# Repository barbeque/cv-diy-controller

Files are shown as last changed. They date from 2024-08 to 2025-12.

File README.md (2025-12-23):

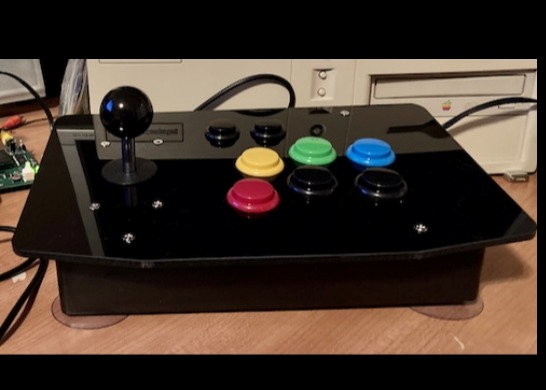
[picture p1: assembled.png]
The assembled joystick.


## Introduction

The stock "Hand Controller" on the ColecoVision is prone to wearing out. It is also uncomfortable to play for long periods of time, due to the position that your hand has to be placed into.

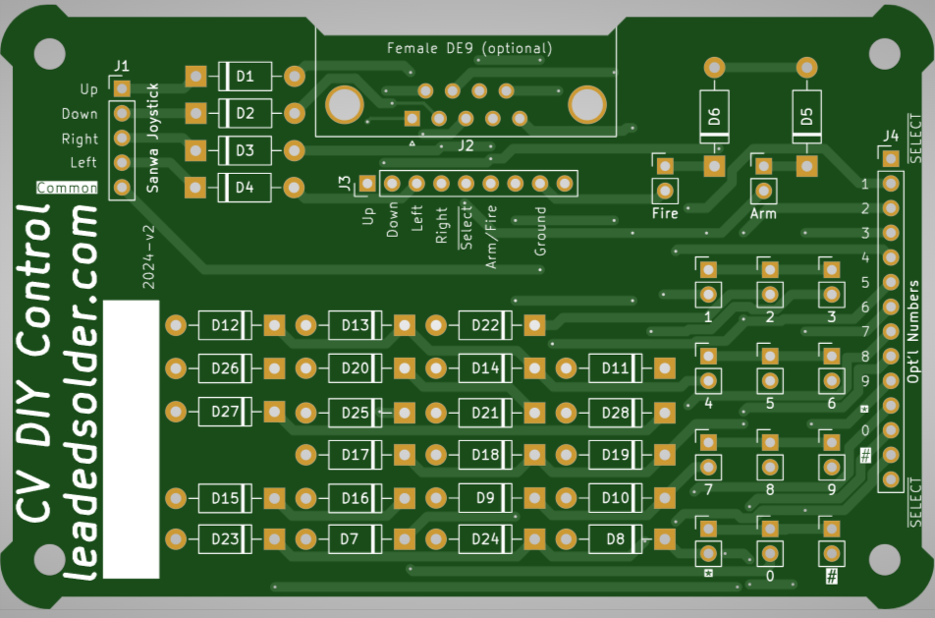
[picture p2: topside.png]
The topside of the PCB.


This PCB allows you to use a generic "arcade joystick kit" to build an arcade-style joystick for the ColecoVision. It makes it much easier to play.

## Version History
### 2024-v2
Diodes were flipped to actually make the PCB work properly. Mea culpa!

Board was shrunk below 100x100mm to make ordering cheaper.

## Support
If you liked this joystick, please [consider supporting my Patreon](https://www.patreon.com/leadedsolder) or [buying me a ko-fi](https://ko-fi.com/leadedsolder). Every penny goes back into making more free and open-source hardware for old computers and game systems.

## Ordering the PCB
Download the Gerber files from [the Releases page](/releases) and send them to your favourite PCB manufacturer.

You can also [order the PCB from PCBWay directly](https://www.pcbway.com/project/shareproject/ColecoVision_DIY_arcade_joystick_PCB_e30ae2ff.html); I will receive a small cut of this price.

## Bill of Materials

| Part | Quantity | Comment |
|---|---|---|
| 1n5817 Schottky diode  | 28 | You can also use 1n4148, which is cheaper |
| A-DF 09 A/KG-T2S male DE9 | 1 | For use with a Sega extension cable. |
| 0.1" male pin headers  | At least 40 | |

## Required Joystick Parts

In addition to the parts listed in the bill of materials, you will need to make sure that your joystick kit comes with buttons, and a Sanwa-style joystick.

The number pad can either be wired to individual buttons (I recommend wiring "1" and "*" at the very least) but some number pads will come with a multi-pin connector, which can then use the large connector on the side.

The female DE9 connector is meant to be used with a Sega Genesis controller extension cable, which is available on many sites like eBay and AliExpress. This will provide the correct pinout to the ColecoVision without having to do any messy cable-building, and you can keep the male end of the cable inside the joystick housing.

You can also wire your own cable into the 9-pin header in the middle of the board.

## Assembly

Break up your pin headers and solder them into the 2-pin connectors for number pad, ARM and FIRE buttons, and the joystick.

Fill every diode space with diodes. If you can't find 1n5817 Schottky diodes, it is OK to use the much more common (and cheaper) 1n4148.

Now it's time to assemble the joystick: put the case together according to the instructions that came with your joystick kit. Once that's done, remove the lid and install the PCB.

Check your joystick's connector. You may need to use a continuity test on your multimeter to figure out which pin is ground and which pins correspond to the directional microswitches. Make sure to install the stick the same way that the label on the board indicates.

Buttons can be connected to the 2-pin pin headers in either orientation: they are not polarized.

## Testing

The best game to test this joystick with is Frenzy, because it has some challenging diagonal directions in order to aim and fire around corners.

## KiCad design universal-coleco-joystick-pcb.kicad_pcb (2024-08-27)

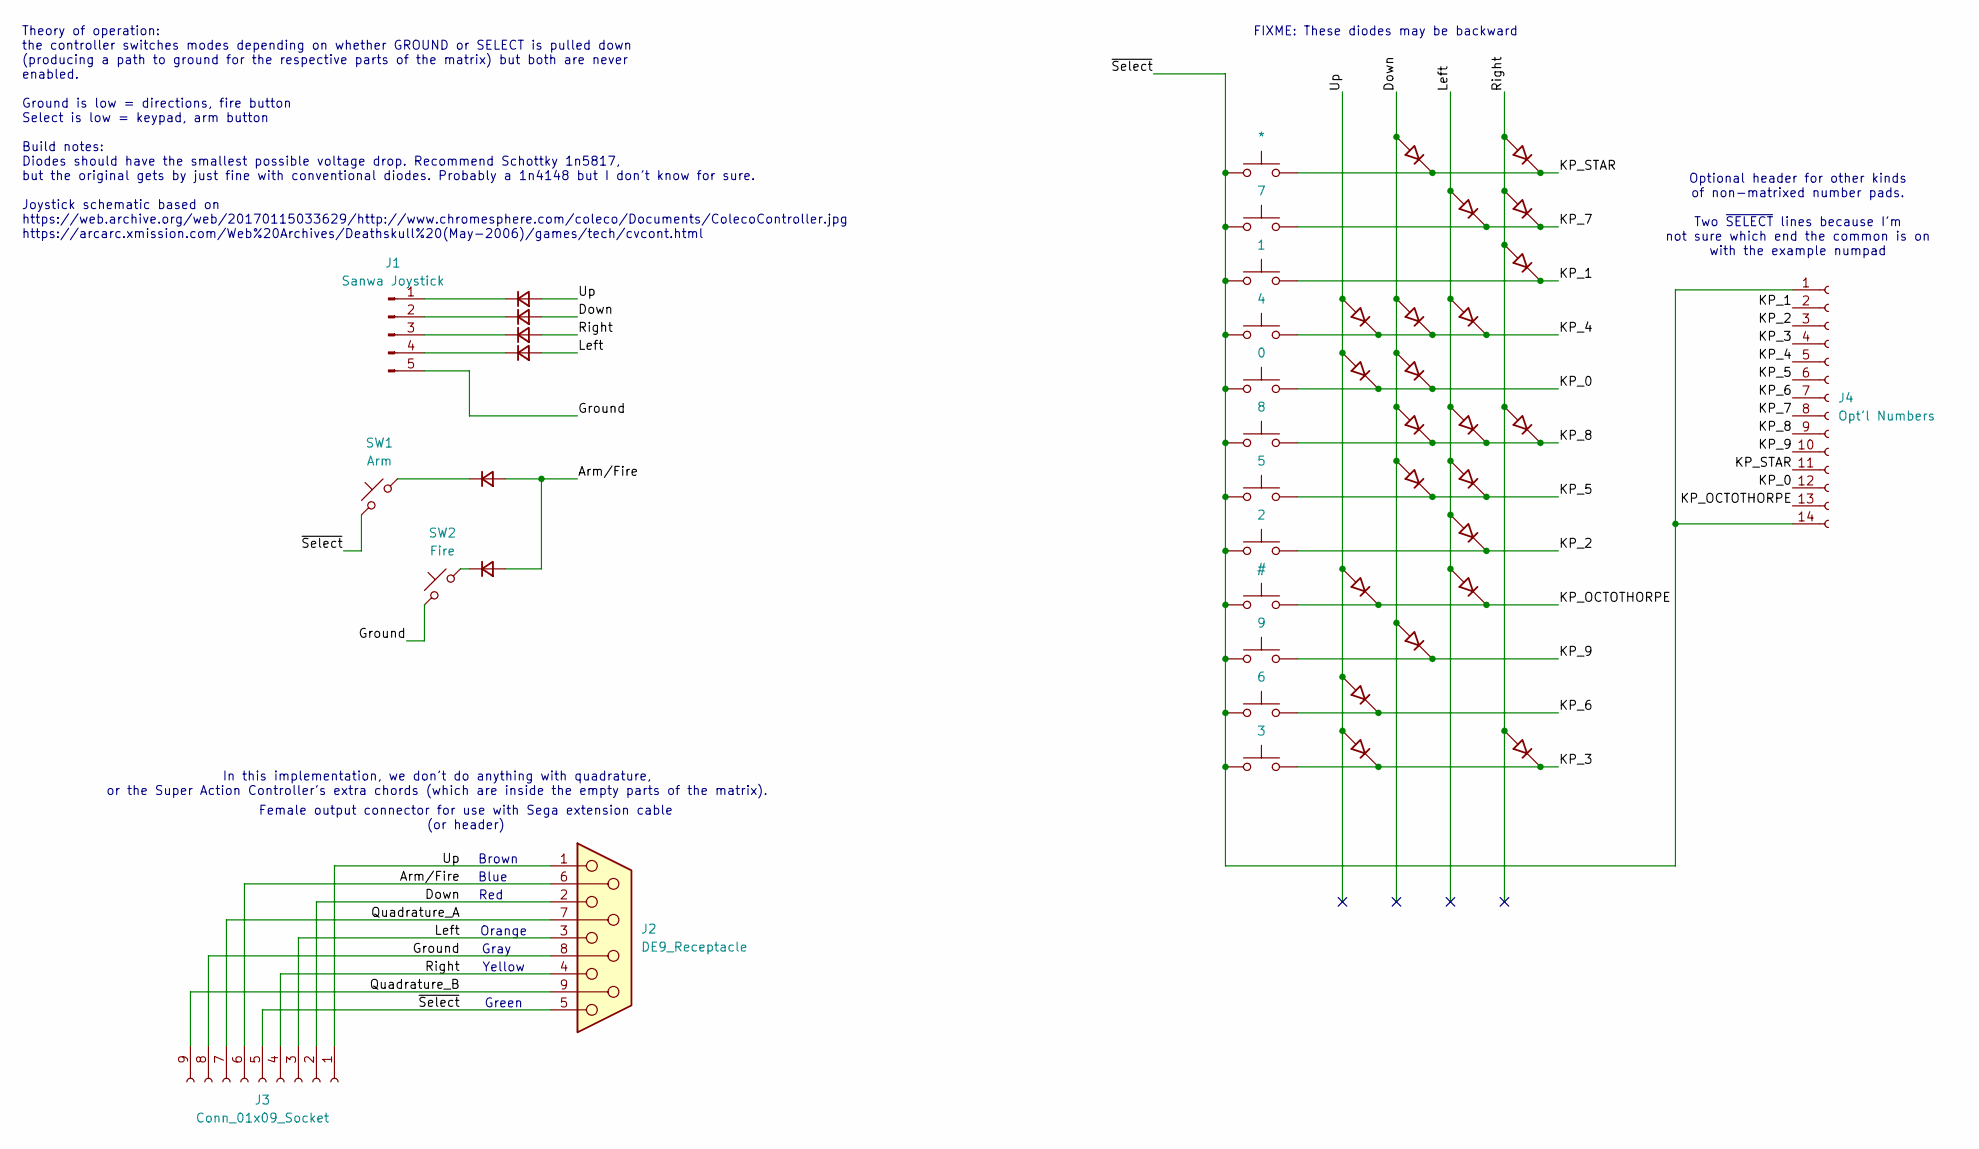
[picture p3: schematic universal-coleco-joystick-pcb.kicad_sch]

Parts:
D1, D2, D3, D4, D5, D6: D_Small; D_DO-41_SOD81_P10.16mm_Horizontal
D7, D8, D9, D10, D11, D12, D13, D14, D15, D16, D17, D18, D19, D20, D21, D22, D23, D24, D25, D26, D27, D28: D_45deg; D_DO-41_SOD81_P10.16mm_Horizontal
J1: Sanwa Joystick; PinHeader_1x05_P2.54mm_Vertical
J2: DE9_Receptacle; DSUB-9_Female_Horizontal_P2.77x2.84mm_EdgePinOffset7.70mm_H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
J3: Conn_01x09_Socket; PinHeader_1x09_P2.54mm_Vertical
J4: Opt'l Numbers; PinHeader_1x14_P2.54mm_Vertical
SW1: Arm; PinHeader_1x02_P2.54mm_Vertical
SW2: Fire; PinHeader_1x02_P2.54mm_Vertical
SW3: *; PinHeader_1x02_P2.54mm_Vertical
SW4: 7; PinHeader_1x02_P2.54mm_Vertical
SW5: 1; PinHeader_1x02_P2.54mm_Vertical
SW6: 4; PinHeader_1x02_P2.54mm_Vertical
SW7: 0; PinHeader_1x02_P2.54mm_Vertical
SW8: 8; PinHeader_1x02_P2.54mm_Vertical
SW9: 5; PinHeader_1x02_P2.54mm_Vertical
SW10: 2; PinHeader_1x02_P2.54mm_Vertical
SW11: #; PinHeader_1x02_P2.54mm_Vertical
SW12: 9; PinHeader_1x02_P2.54mm_Vertical
SW13: 6; PinHeader_1x02_P2.54mm_Vertical
SW14: 3; PinHeader_1x02_P2.54mm_Vertical

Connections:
/Arm/Fire: D5.2 (A), D6.2 (A), J2.6, J3.6
/Down: D2.2 (A), D7.2 (A), D13.2 (A), D16.2 (A), D17.2 (A), D20.2 (A), D25.2 (A), J2.2, J3.2
/Ground: J1.5, J2.8, J3.8, SW2.2
/KP_0: D15.1 (K), D16.1 (K), J4.12, SW7.2
/KP_1: D11.1 (K), J4.2, SW5.2
/KP_2: D22.1 (K), J4.3, SW10.2
/KP_3: D27.1 (K), D28.1 (K), J4.4, SW14.2
/KP_4: D12.1 (K), D13.1 (K), D14.1 (K), J4.5, SW6.2
/KP_5: D20.1 (K), D21.1 (K), J4.6, SW9.2
/KP_6: D26.1 (K), J4.7, SW13.2
/KP_7: D9.1 (K), D10.1 (K), J4.8, SW4.2
/KP_8: D17.1 (K), D18.1 (K), D19.1 (K), J4.9, SW8.2
/KP_9: D25.1 (K), J4.10, SW12.2
/KP_OCTOTHORPE: D23.1 (K), D24.1 (K), J4.13, SW11.2
/KP_STAR: D7.1 (K), D8.1 (K), J4.11, SW3.2
/Left: D4.2 (A), D9.2 (A), D14.2 (A), D18.2 (A), D21.2 (A), D22.2 (A), D24.2 (A), J2.3, J3.3
/Quadrature_A: J2.7, J3.7
/Quadrature_B: J2.9, J3.9
/Right: D3.2 (A), D8.2 (A), D10.2 (A), D11.2 (A), D19.2 (A), D28.2 (A), J2.4, J3.4
/Up: D1.2 (A), D12.2 (A), D15.2 (A), D23.2 (A), D26.2 (A), D27.2 (A), J2.1, J3.1
/~Select: J2.5, J3.5, J4.1, J4.14, SW1.2, SW3.1, SW4.1, SW5.1, SW6.1, SW7.1, SW8.1, SW9.1, SW10.1, SW11.1, SW12.1, SW13.1, SW14.1
unnamed: D1.1 (K), J1.1
unnamed: D2.1 (K), J1.2
unnamed: D3.1 (K), J1.3
unnamed: D4.1 (K), J1.4
unnamed: D5.1 (K), SW1.1
unnamed: D6.1 (K), SW2.1

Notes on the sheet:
Optional header for other kinds of non-matrixed number pads. Two ~{SELECT} lines because I'm not sure which end the common is on with the example numpad
Theory of operation: the controller switches modes depending on whether GROUND or SELECT is pulled down (producing a path to ground for the respective parts of the matrix) but both are never enabled. Ground is low = directions, fire button Select is low = keypad, arm button Build notes: Diodes shou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
Green
Blue
Brown
Female output connector for use with Sega extension cable (or header)
Red
In this implementation, we don't do anything with quadrature, or the Super Action Controller's extra chords (which are inside the empty parts of the matrix).
FIXME: These diodes may be backward
Yellow
Gray
Orange

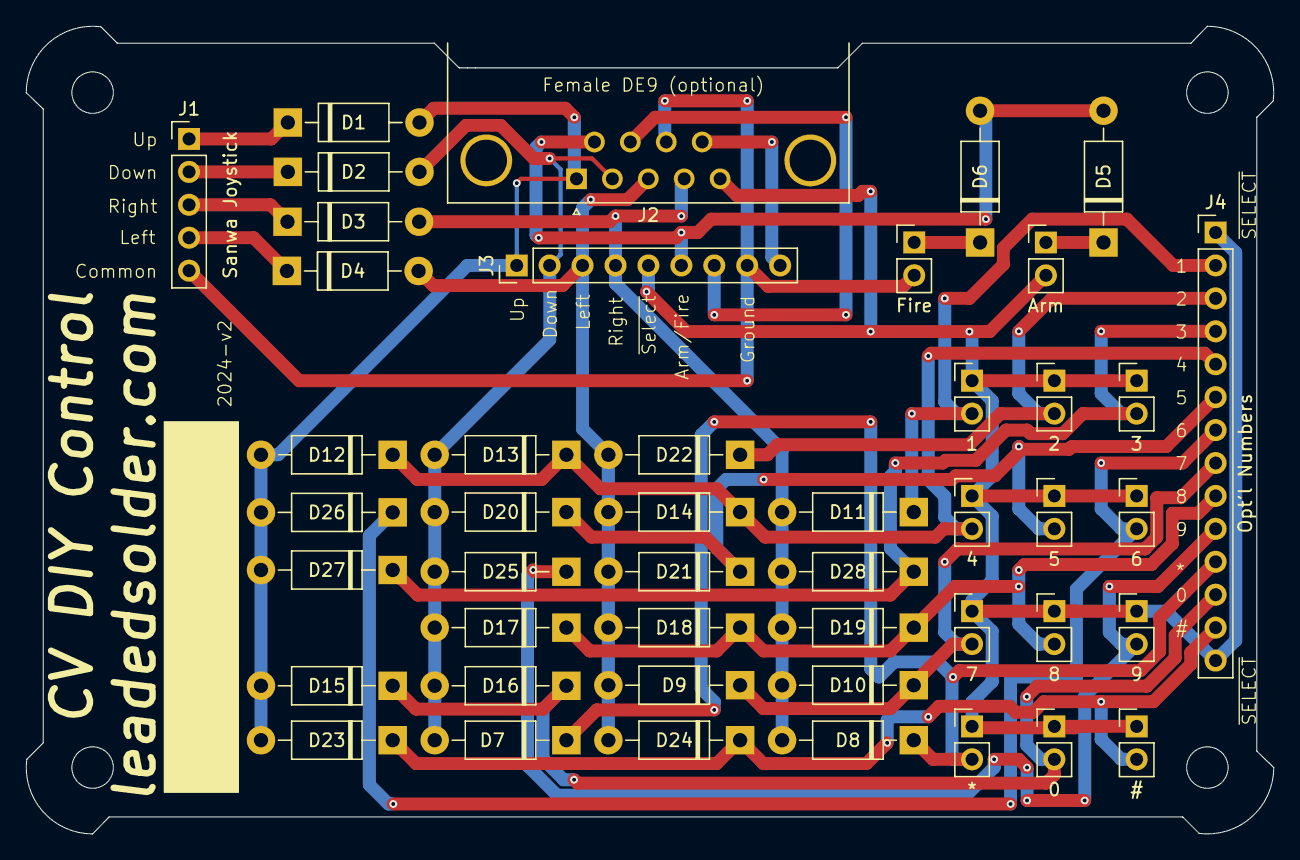
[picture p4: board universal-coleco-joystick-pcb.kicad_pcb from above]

Board: 2 copper layers, 96.2 x 62.3 mm, 46 parts (0 on the bottom side), 27 nets.

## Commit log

2024-06-26 Schematic hashed out
    [universal-coleco-joystick-pcb.kicad_pcb, universal-coleco-joystick-pcb.kicad_sch]
2024-06-26 Diode soup
    [universal-coleco-joystick-pcb.kicad_pcb, universal-coleco-joystick-pcb.kicad_sch]
2024-06-26 Fix unsightly labels
    [universal-coleco-joystick-pcb.kicad_pcb]
2024-06-27 Linear KP header
    [universal-coleco-joystick-pcb.kicad_pcb, universal-coleco-joystick-pcb.kicad_sch]
2024-07-01 Release v1 to JLC
    [universal-coleco-joystick-pcb.kicad_pcb]
2024-07-21 Warning: Diodes may be backward for number matrix
    [universal-coleco-joystick-pcb.kicad_sch]
2024-08-26 UDRL not UDLR joystick error
    [universal-coleco-joystick-pcb.kicad_pcb, universal-coleco-joystick-pcb.kicad_sch]
2024-08-27 Diodes flipped, board shrunk below 100x100
    [universal-coleco-joystick-pcb.kicad_pcb, universal-coleco-joystick-pcb.kicad_sch]
